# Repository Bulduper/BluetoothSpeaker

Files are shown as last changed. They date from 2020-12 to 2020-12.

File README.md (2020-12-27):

# Bluetooth Speaker

Photo of final result - v1.0 Bluetooth Speaker

### *Disclaimer*

This is not a regular github repository. You may consider it as a blog entry. Here, in this *readme*, I share my experience with designing a 3d printed bluetooth speaker. The code I uploaded runs on Atmega328P on the main board of the speaker.

## The goal
I wanted to have a wireless, convenient bluetooth speaker. So simple! So many people use them. I could have just bought one for like 100$, enjoy a decent sound quality and no maintenance issues.
Boooooring...

>I am curious how difficult it is to design and make a consumer electronics product like those we can buy on the market. *~ my thought, 2018*

The point was to try buliding a complete product with no expensive nor advanced technology. My workshop had to be enough!

Having a 3D printer and some inner motivation I challenged myself to create a bluetooth speaker which would meet the following criteria:
- 3D printed, as much as possible
- plays music!
- looks good (a more sophisticated design than speakers in a breakfast box)
- no wires sticking out the case, no duct tape, **no quick fix**
- can be used as comfortably as a commercial one

The general idea was to make a speaker like e.g. JBL Flip in terms of basic principals. And those were:
- two front speaker drivers
- two side passive speakers
- airtight
- wireless - bluetooth connection and no power cord
- convinient charging
- battery level indicator
- roughly the size of a 0.5l water bottle

## First try
My first design was successfull in some way.
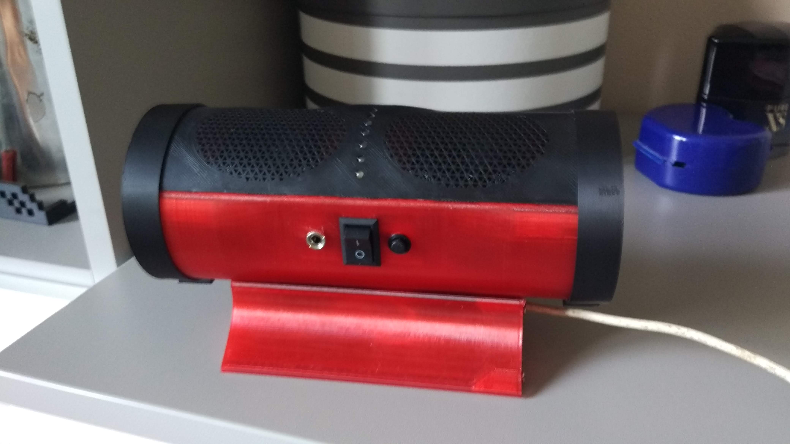
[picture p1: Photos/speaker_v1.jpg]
Photo of speaker v1.0 Version 1.0

It worked, played music and basically met almost all the requirements to some extent. And to some extent only...
- it was not airtignt enough, a significant amount of air was leaking
- very inconvenient to assemble
- not really good looking
- it did not have visible quick fixes, but inside THERE WAS JUST A MESS

All the mentioned drawbacks were too much and so the build was unreliable. 

## Problems around batteries and charging
The battery of choice happens to be a Lithium Ion 18650 cell.
It's rated for 3.7V (max 4.2V) and has a good energy density. Also it is cheap and popular. Lithium Ion cells are kinda fussy, though. To keep them in good condition they need:
- constant current / constant voltage charging
- ballanced voltage between cells (if more than one)
- some protection against dangerously low voltage

I only needed to provide 12 volts to the amplifier and there came the first problem. I could either connect 3 18650 cells in series or boost the voltage with a boost converter. The latter solution turned out to be ineffective, as I didn't have (and couldn't find) a step up converter that would provide enough power for such a voltage difference. At higher volume there were power cutoffs.
The first idea however ruined my ideal, effortless charging concept. 

Ideally I wanted the speaker to be charged with a standard 5V wall charger. This is easily obtainable with a single lithium cell (opitonally multiple, in parallel). Thus, keeping the series cell connection, I had to abandon this way of charging.

My first attempt was to charge each cell individually with a TP4056 charging module for each one. In order for it to be possible (while keeping the cells in series) I had to power each module individually with a galvanically isolated wall charger, again for each one. I ended up having a custom charger box supplied with mains voltage which included 3 wall chargers. Very inelegant solution.

Finally I changed the concept and hooked up a 3S Battery Management System board. It's job is to ballance cell's voltage at the end of charging and stop the current flow in case of short circuit or over-discharge. To provide a recommended charging program I bought a 12,6V LiIon wall CC/CV charger.

## LEDs are cool
Well, at some point I decided it would be cool to have RGB LEDs dancing to the music. The lights had to be visible, so I printed the case with a transparent filament. I made some tests on audio processing by a microcontroller unit so that LEDs could react to the music beat. It tured out working quite well so I implemented the feature to the circuit and 3d design.

## DIY PCB
I didn't really like my first electronics arrangement. I just soldered all components on a ~~good~~ old breadboard. Is was very messy, little wires everywhere, so much to go wrong.

My plan was to try making my first own printed circuit borard. Not only am I talking about the design, but also about the manufacturing. I used a chemical transfer technique to place the tracks and pads on a copper covered board. I used a solution of sodium persulfate for etching. Then I drilled the through-holes with a dremel on vertical press. Soldering was just a pleasure.

So, the final circuit can be found [here for the main board](https://oshwlab.com/dawid199912/bluetoothspeaker_v2_custompcb) and [here for the top board](https://oshwlab.com/dawid199912/bluetoothspeaker_v2_toppanelpcb)

## Components

I bought most of the parts on Aliexpress. I had absolutely no confidence they would work together and produce a good sound quality.

1. 10W 4 Ohm 1.5inch speaker drivers - [Aliexpress link](https://www.aliexpress.com/item/32816810056.html?spm=a2g0s.9042311.0.0.27424c4d4MThSE)
2. Passive speakers - [Aliexpress link](https://www.aliexpress.com/item/32828412002.html?spm=a2g0s.9042311.0.0.27424c4d4MThSE)
3. Audio amplifier module based on 2x15W TPA3110
4. KRC-86b bluetooth audio module
5. ATMEGA 328P microcontroller

## Final(?) result
Now, considering all the difficulties I mentioned here and those I didn't mention, I must say I'm happy with the final result.

[LINK TO THE DEMO VIDEO](https://youtu.be/Gikhf-romf0)

There are some compromises against my initial plan I accepted such as:
- still not completely airtight
- use of hotglue to seal the connectors
- sound quality is just ok
- there is some resonance at high tones, mainly caused by loose top cover and wires inside the case
- audible noise when no music played 

## Summary
This project has let me explore so many branches of engineering - starting from 3d modeling, through batteries and charging management, ending up with pcb design and manufacturing.
I spent quite a lot of time solving minor problems with the 3d model and tweaking the code and values for LEDs. I got to the point where I still see so much room for improvement, but I'm happy with the result already. I will potentially keep on developing this project when I notice any interest from the community.

I hope I won't get kicked from github for this blog-ish entry ;)

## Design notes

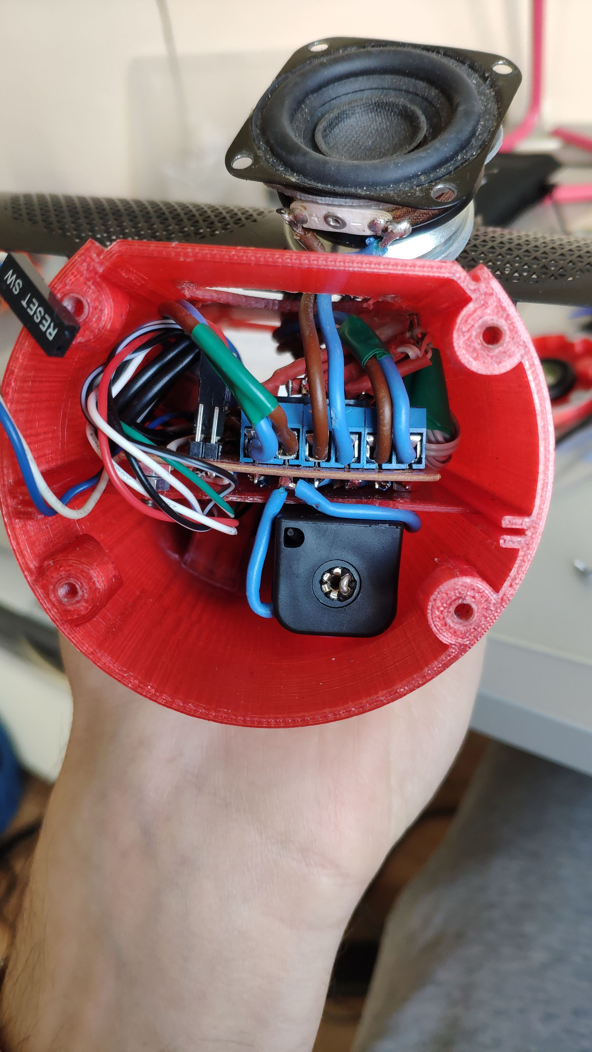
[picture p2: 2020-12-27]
Photos/speaker_v1_mess.jpg

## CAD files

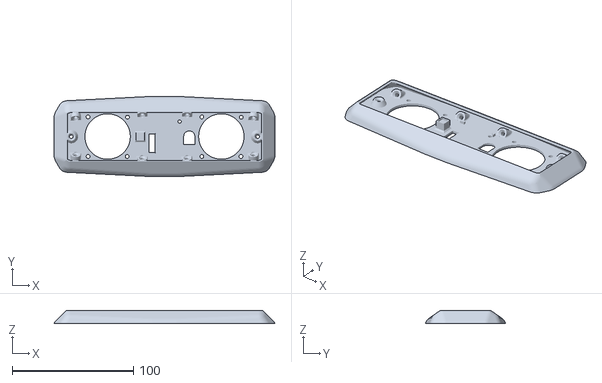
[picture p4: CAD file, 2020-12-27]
3d files/Main_topBody.stl
182.6 x 66.4 x 10.9

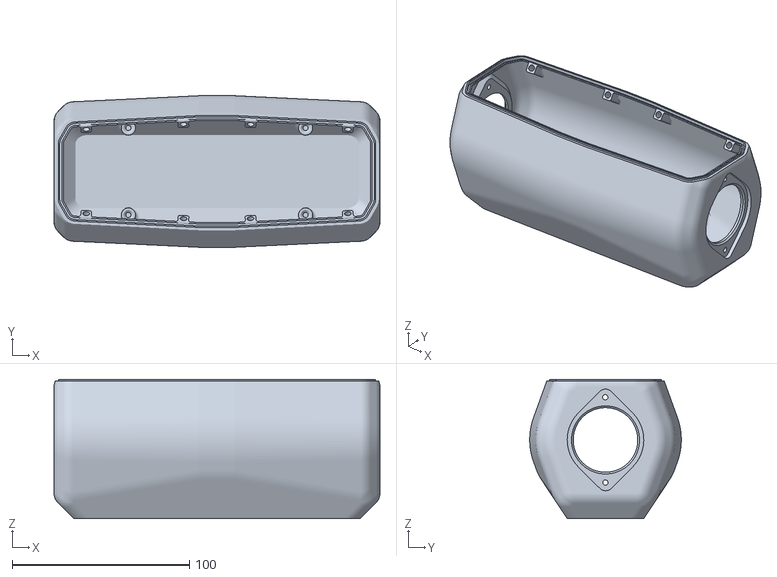
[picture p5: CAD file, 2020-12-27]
3d files/BottomMain_v2_1.stl
184.0 x 85.6 x 78.6

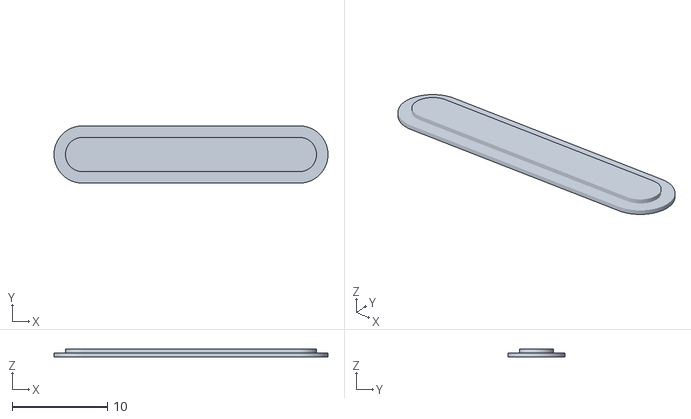
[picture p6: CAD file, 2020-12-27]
3d files/ledCover_Transparent.stl
28.7 x 6.00 x 0.8

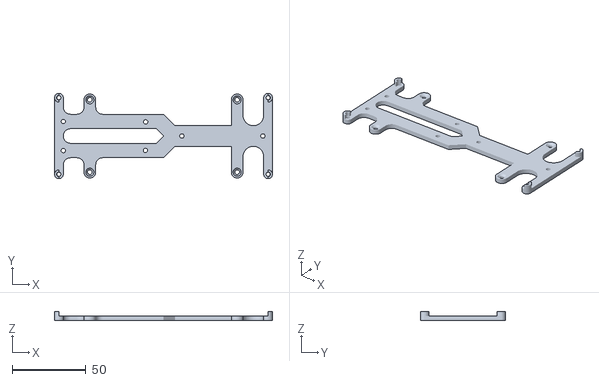
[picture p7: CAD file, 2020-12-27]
3d files/Batteries&pcb support.stl
148.0 x 58.0 x 6.00

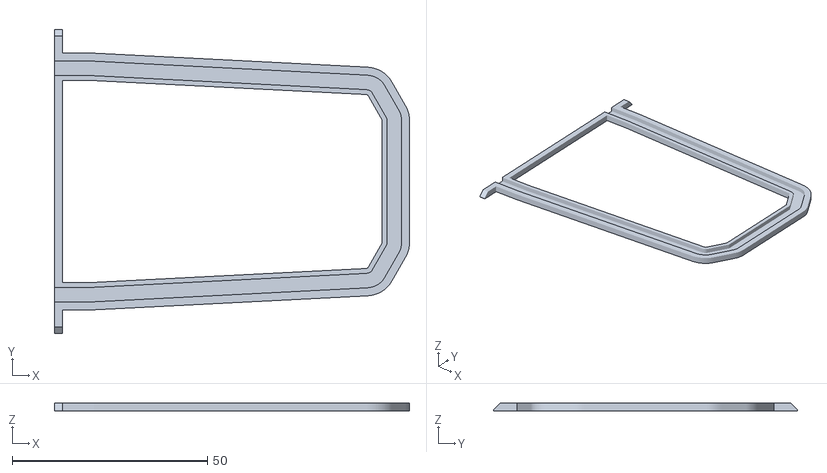
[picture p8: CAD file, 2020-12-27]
3d files/siliconeGasket_mold.stl
90.8 x 77.7 x 2.00

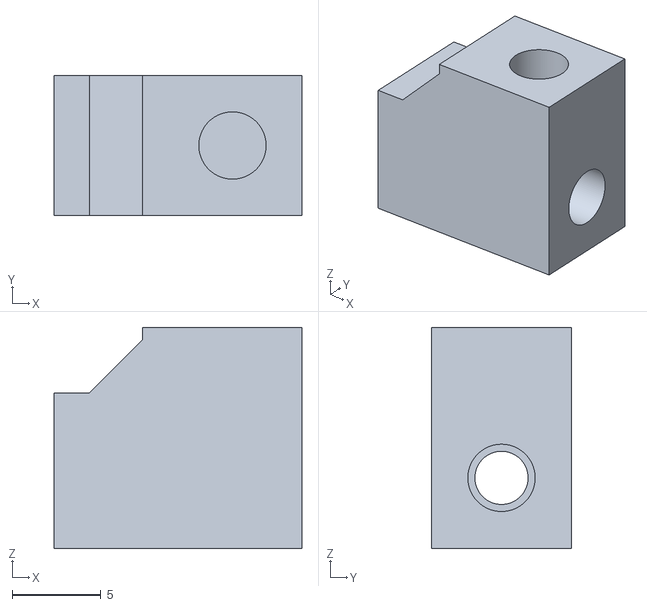
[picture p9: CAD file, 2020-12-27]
3d files/TopToBottom_sideCoupler.stl
14.0 x 7.93 x 12.5

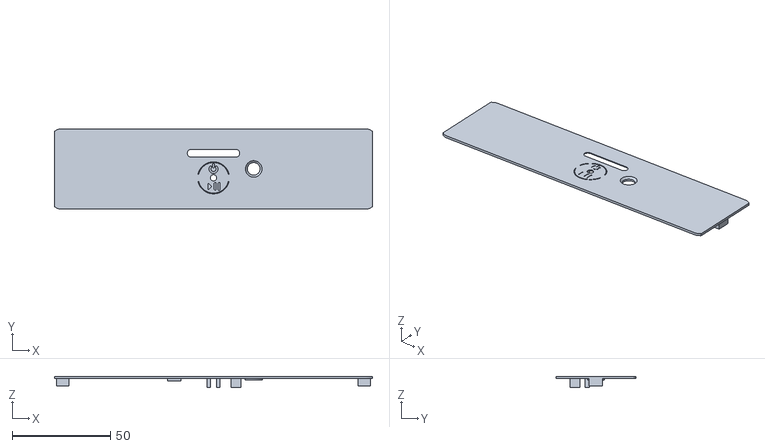
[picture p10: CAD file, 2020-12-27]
3d files/TopCover_solid.stl
161.9 x 40.9 x 5.76

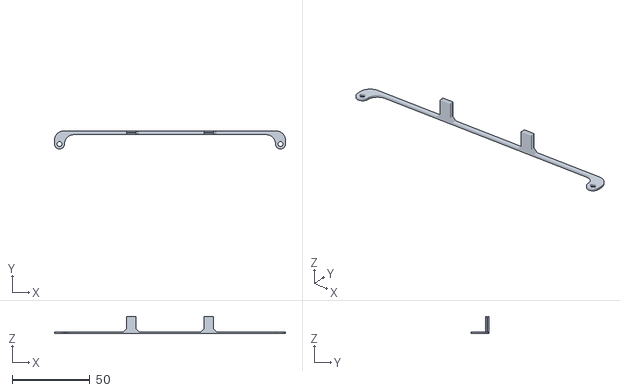
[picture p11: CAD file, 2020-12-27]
3d files/LED Strip Support.stl
148.4 x 11.6 x 11.2

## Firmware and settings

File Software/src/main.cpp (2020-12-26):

#include <Arduino.h>
#include <DancingRGBs.h>
#include <OneButton.h>

#define WLED1 8
#define WLED2 9
#define WLED3 10
#define WLED4 11
#define WLED5 12
#define WLED6 13
#define GLED 7

#define STRIPLED_R 6
#define STRIPLED_G 5
#define STRIPLED_B 3

#define BTN A3
#define PAUSE 4
#define MUTE A2
#define BT_INFO 2             //there is a problem, it does not work due to strange voltage lvls on CSR LED

#define BAT_VOLTAGE A1

#define AUDIOIN A0

#define VCC 5.000f
#define LONG_PRESS_MS 500
#define BAT_VOL_OFFSET 0.163   //this value must be added to the battery voltage, it was obtained experimentally  

float bat_voltage;
float batteryThresholds[6]={3.4f, 3.6f, 3.7f, 3.75f, 3.85f, 3.95f};
int currentBatteryLvl;

bool batteryOK = true;
bool btnIsPressed;

unsigned long lastInterruptPressed, lastInterruptReleased;
unsigned long lastLoop_30s = -30000;

DancingRGBs dancingRGBs(STRIPLED_R,STRIPLED_G, STRIPLED_B);
OneButton button = OneButton(BTN);

void initialSequence();
void errorBlink();
void Loop_30s();
void measureVoltage();
void updateBatteryLvl();
void displayBatteryLvl();
void pauseResume();
void longPressResult();
void whiteLeds(byte Byte);

void setup() {

  Serial.begin(9600);
  pinMode(BTN,INPUT_PULLUP);
  pinMode(BT_INFO,INPUT);
  pinMode(PAUSE,OUTPUT);
  pinMode(MUTE,OUTPUT);
  pinMode(GLED,OUTPUT);
  pinMode(STRIPLED_R,OUTPUT);
  pinMode(STRIPLED_G,OUTPUT);
  pinMode(STRIPLED_B,OUTPUT);

  digitalWrite(PAUSE,LOW);
  digitalWrite(MUTE, HIGH);
  digitalWrite(GLED,HIGH);

  button.attachClick(pauseResume);
  button.attachLongPressStop(longPressResult);
  button.setPressTicks(LONG_PRESS_MS);
  delay(500);
  initialSequence();
}

void loop() {
  Loop_30s();
  button.tick();
  if(batteryOK)dancingRGBs.loop();
  else
  {
    digitalWrite(MUTE,LOW);
    errorBlink();
  }

  //Serial.println(analogRead(AUDIOIN));
}

void initialSequence()
{
  whiteLeds(0);
  delay(200);
  whiteLeds(0b001100);
  delay(200);
  whiteLeds(0b010010);
  delay(200);
  whiteLeds(0b100001);
  delay(200);
  whiteLeds(0b110011);
  delay(200);
  whiteLeds(0b111111);
  delay(200);
}

void errorBlink()
{
  whiteLeds(0);
  digitalWrite(GLED,LOW);
  delay(300);
  whiteLeds(0b111111);
  digitalWrite(GLED,HIGH);
  delay(300);
}


void Loop_30s()
{
  if(millis()-lastLoop_30s>30000)
  {
    measureVoltage();
    updateBatteryLvl();
    displayBatteryLvl();
    /*Serial.print(bat_voltage);
    Serial.print("\n");*/
    lastLoop_30s = millis();
  }

}

void measureVoltage()
{
  float bat_avg;
  float analogToVolts = 1023.0F/VCC;
  bat_avg=0;



  ADMUX = 0b01000000 | 1;       // use pin A1 and Vcc voltage reference
  ADCSRA = 0b11010101;      // set ADC

  while(!(ADCSRA & 0x10));        // wait for ADC to complete current conversion ie ADIF bit set
  ADCSRA = 0b11010101 ;               // clear ADIF bit so that ADC can do next operation (0xf5)
  for(int i = 0; i<10; i++)
  {
    
    while(!(ADCSRA & 0x10));        // wait for ADC to complete current conversion ie ADIF bit set
    bat_avg+=ADC;
    //Serial.println(ADC);
    ADCSRA = 0b11010101 ;               // clear ADIF bit so that ADC can do next operation (0xf5)

  }
  while(!(ADCSRA & 0x10));        // wait for ADC to complete current conversion ie ADIF bit set
  ADMUX = 0b00000000;       // use pin A0 (update for audio input readings) and external voltage reference - A PART OF THE SOLUTION BELOW
  

  //////  THIS IS A SOLUTION TO THE PEAKS READ BY ADC ON A0 AFTER ADMUX UPDATE
  //////  1000 READINGS TAKE APPROX. 28ms AND I DON'T LIKE IT, BUT IT WAS THE ONLY APPROACH THAT WORKED FOR ME :/ 
  for(int i= 0; i<1000; i++)
  {
  ADCSRA = 0b11010101;      // set ADC
  while(!(ADCSRA & 0x10));        // wait for ADC to complete current conversion ie ADIF bit set
  }

  bat_avg/=10.f;


  float bat1_v = bat_avg/analogToVolts;

  bat_voltage = bat1_v+BAT_VOL_OFFSET;
}

void updateBatteryLvl()
{
  const int deadBand = 0.02f;
  int i=0;

  if(bat_voltage<=3.3f)
  {
    batteryOK = false;

    return;
  }
  batteryOK = true;
  digitalWrite(MUTE,HIGH);

  while(bat_voltage>batteryThresholds[i])
  {
    i++;
    if(i>=6)break;
  }
  
  //histeresis
  if(currentBatteryLvl<i)
  {
    if(bat_voltage>batteryThresholds[i-1]+deadBand)currentBatteryLvl = i;
  }
  else if(currentBatteryLvl>i)
  {
    if(bat_voltage < batteryThresholds[i] - deadBand)currentBatteryLvl = i;
  }

}

void displayBatteryLvl()
{
  whiteLeds((1<<currentBatteryLvl)-1);
}

void whiteLeds(byte Byte)
{
  int ledNo = 0;
  while(ledNo<6)
  {
    switch (ledNo)
    {
    case 0:
      digitalWrite(WLED1,Byte%2);
      break;
    case 1:
      digitalWrite(WLED2,Byte%2);
      break;
    case 2:
      digitalWrite(WLED3,Byte%2);
      break;
    case 3:
      digitalWrite(WLED4,Byte%2);
      break;
    case 4:
      digitalWrite(WLED5,Byte%2);
      break;
    case 5:
      digitalWrite(WLED6,Byte%2);
      break;
    default:
      break;
    }
    Byte/=2;
    ledNo++;
  }
}

void pauseResume()
{
  digitalWrite(PAUSE,HIGH);
  delay(100);
  digitalWrite(PAUSE,LOW);
}

void longPressResult()
{
  dancingRGBs.nextMode();
}

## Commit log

2020-09-07 Interrupt implementation (short/long press)
    [main.cpp]
2020-12-26 Another approach for dancing leds, new readme
2020-12-27 Added 3d files and photos
    [Batteries&pcb support.stl, BottomMain_v2_1.stl, LED Strip Support.stl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]
